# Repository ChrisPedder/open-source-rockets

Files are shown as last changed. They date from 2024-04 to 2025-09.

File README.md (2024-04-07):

# las_rocket_project
A repository for design files for the maker's workshop at LAS.

## Recommended software

To use the files in this repository, I recommend that you open the .ork file using [openrocket](https://openrocket.info/) which will allow you to view and modify the rocket design.

To create new nosecone designs, use the nosecone_factory.scad file, which can be opened with [openscad](https://openscad.org/). Scad format allows you to define .stl files in code, which makes it much easier to create parametrisable versions of things like nosecone designs.

Note that that nosecone is designed to be printed in PLA, with a wall thickness of 0.2mm, and with an infill density of 20%.

The nosecone_factory.scad is not my own work, but was created by Thingiverse user TZT, and is used here under Creative Commons - Attribution license.

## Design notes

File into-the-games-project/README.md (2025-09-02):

# Into the Games Rocket

An open source model rocket project designed for educational purposes and recreational flying. This rocket uses readily available components and 3D printed parts to create a stable, recoverable rocket suitable for D-class motors.

## Project Overview

This rocket is designed around a 50mm diameter mailing tube body with 3D printed motor mount, nose cone, and fin attachment system. The design prioritizes simplicity, safety, and repeatability while maintaining good aerodynamic performance.

**Key Specifications:**
- Body diameter: 50mm
- Motor: 18mm diameter (Klima D9-3 recommended)
- Recovery: 30cm parachute with kevlar shock cord
- Fin material: 4mm plywood
- Estimated flight altitude: ~150m (dependent on motor and conditions)

## Repository Contents

### Design Files

#### `into-the-games-rocket.ork`
OpenRocket simulation file containing the complete rocket design, stability analysis, and flight simulations.

**How to open:** Download and install [OpenRocket](http://openrocket.sourceforge.net/) (free, cross-platform), then open this .ork file to view simulations, modify the design, or analyze different motor configurations.

**What it contains:**
- Complete 3D model of the rocket
- Center of gravity and pressure calculations
- Stability margin analysis
- Flight simulation data for various motors
- Recovery system deployment timing

#### `fin-shape.svg`
Laser cutter template for the rocket fins.

**How to open:** Any vector graphics program (Inkscape, Adobe Illustrator, or even a web browser)

**Usage:** Send this file directly to a laser cutter set for 4mm plywood. The design includes 3 identical fins.

### 3D Printable Parts

All STL files are ready for 3D printing in PLA plastic with standard settings (0.2mm layer height, 20% infill).

#### `motor-mount.stl` / `motor-mount.scad`
**Purpose:** Houses the 18mm motor and provides attachment point for recovery system
**Features:**
- Precise 18mm motor tube fit
- Drill two 3mm holes in the top mounting ring shock cord attachment point
- Designed for friction fit into 50mm body tube, attachment with pva glue

#### `nose-cone.stl` / `nose-cone.scad`
**Purpose:** Aerodynamic nose cone with recovery system compartment
**Features:**
- Ogive shape for optimal aerodynamics
- Hollow interior, drill two 3mm holes for shock cord attachment
- Friction fit to body tube

#### `screw-cap.stl`
**Purpose:** Removable cap for motor mount access
**Features:** Threaded design for secure motor retention and easy motor changes

#### `fin-guide.stl`
**Purpose:** Alignment jig for precise fin attachment
**Features:** Ensures proper fin angle and spacing during assembly

### OpenSCAD Source Files

The `.scad` files are parametric source code for the 3D printed parts.

**How to open:** Download [OpenSCAD](https://openscad.org/) (free, open source)

**Benefits:**
- Modify dimensions for different body tubes or motors
- Adjust tolerances for your specific 3D printer
- Customize features like shock cord attachment points
- Generate parts for scaled versions

## Required Components

### Body Tube
**Part:** Mailing tube with plastic caps (50mm inner diameter × 310mm length)
**Source:** [Galaxus.ch](https://www.galaxus.ch/en/s12/product/kaiserkraft-mailing-tube-with-plastic-cap-and-base-lx-310-x-50-mm-brown-30-items-1-x-cardboard-boxes-43762165)
**Quantity:** 1 tube
**Notes:** Brown cardboard construction, includes plastic end caps

### Fins
**Material:** 4mm plywood
**Source:** Local laser cutting service or makerspace
**Quantity:** 3 fins (cut from `fin-shape.svg`)
**Dimensions:** Approximately 100mm × 80mm per fin

### 3D Printed Components
**Material:** PLA plastic
**Print Settings:**
- Layer height: 0.2mm
- Infill: 20%
- Supports: Only for nose cone if needed
**Parts:** Motor mount, nose cone, screw cap, fin guide

### Recovery System
**Parachute:** 30cm diameter
**Source:** [Amazon.de](https://www.amazon.de/TranRantic-Parachute-Children-Outdoor-Outdoors/dp/B0F7KQTMBR/)
**Shock Cord:** 1m of 2mm kevlar line
**Notes:** Kevlar is heat-resistant and won't burn from motor ejection charge

### Rail Guide
**Material:** 5mm paper drinking straw
**Length:** ~50mm
**Purpose:** Guides rocket on launch rod during initial acceleration, attached with pva glue

## Flight Components

### Motors
**Recommended:** Klima D9-3 (18mm diameter)
**Source:** [Hobbyshop.ch](https://www.hobbyshop.ch/modellraketen-treibsatz-d9-3-6-stueck-klima0493.html)
**Notes:**
- D9-3 provides good altitude (150m) with 3-second delay for recovery deployment
- Always verify motor fits properly before flight
- Store motors in cool, dry location

### Recovery Wadding
**Purpose:** Protects parachute from hot ejection gases
**Source:** [Hobbyshop.ch](https://www.hobbyshop.ch/schutzwatte-fuer-modellraketen-klima7020.html)
**Usage:** Pack wadding loosely into body tube below parachute before each flight

## Launch Equipment

### Launch Rod
**Specification:** 5mm diameter metal rod, minimum 1m length
**Purpose:** Guides rocket during initial acceleration until fins provide stability

### Safety Equipment
**Fire blanket:** Protects ground from motor flames
**Safety distance:** Minimum 30m from spectators
**Recovery area:** Large open field, minimum 200m radius

## Assembly Instructions
Full instructions and images can be found here (Making_a_rocket.pdf)

1. **Prepare body tube:** Remove plastic end caps, sand lightly if needed for 3D printed parts fit

2. **Attach shock cord to motor mount:** Tie a loop in the cord, one third along the length. Tie the long end of the cord to the two small holes in the motor mount using a figure of 8 knot.

3. **Install motor mount:** Press-fit motor mount into body tube, cord end first, threading the cord through the tube and out the other end. Ensure shock cord attachment is accessible.

4. **Attach shock cord to nose cone:** Tie the other end of the cord to the two small holes in the nose cone using a figure of 8 knot.

5. **Attach parachute:** Tie the end of the parachute lines to the loop already made in the shock cord. Attach with swivel if available.

6.  **Prepare recovery system:** Fold the parachute, wrap the cord around it and place it inside the rocket body tube. Fit the nose cone into the end of the body tube,  ensure smooth separation for recovery.

7. **Glue in motor mount:** Using Epoxy glue, glue the non-cord end of the motor mount into the end of the rocket body tube, so that the end of the motor tube is aligned with the end of the cardboard tube.

8. **Attach fins:** Use fin guide to mark positions, epoxy fins to body tube with 120° spacing. Ensure the end of the shallow sloping side of the fin is lined up with the end of the rocket body tube.

9. **Attach launch lug:** Take one launch lug (piece of drinking straw) and glue it between two fins, halfway along the rocket body tube.

## Pre-Flight Checklist

- [ ] Motor properly installed and retained
- [ ] Recovery wadding packed above parachute
- [ ] Parachute properly folded and not tangled
- [ ] Fin attachment secure
- [ ] Launch rod guide (straw) attached
- [ ] Weight and balance verified using OpenRocket file

## Safety Notes

⚠️ **Important Safety Information:**
- Always follow local regulations for model rockets
- Never attempt to make your own motors
- Inspect all components before each flight
- Maintain safe distances during launch
- Recovery area must be clear of dry vegetation
- Do not fly in high wind conditions (>20 km/h)

## Modifications and Customization

The OpenSCAD files allow easy customization:
- **Different body tubes:** Adjust outer diameter in motor-mount.scad
- **Alternative motors:** Modify motor mount inner diameter
- **Scaled versions:** Proportionally adjust all dimensions
- **Enhanced recovery:** Add dual-deploy or electronic altimeter bay

## Contributing

This is an open source project! Contributions welcome:
- Improved designs or alternative components
- Additional motor configurations
- Better assembly instructions
- Flight test data and photos

## License

This project is released under [Creative Commons Attribution-ShareAlike 4.0](https://creativecommons.org/licenses/by-sa/4.0/). You're free to use, modify, and share these designs as long as you provide attribution and share derivative works under the same license.

## Disclaimer

Model rocketry involves inherent risks. Users are responsible for following all local laws and safety guidelines. Always prioritize safety over performance. The authors are not responsible for damages or injuries resulting from the use of these designs.

---

**First time building rockets?** Consider joining [ARGOS](https://www.argoshpr.ch/j3/) a local rocketry club. The experience and mentorship are invaluable for safe, successful flights.

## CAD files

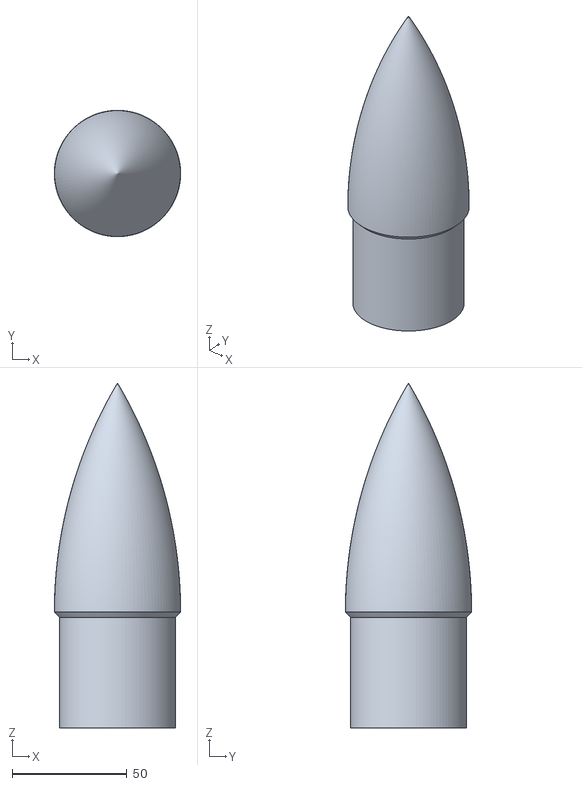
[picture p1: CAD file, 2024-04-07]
las-rocket-project/las_rocket_nosecone.stl
55.1 x 55.1 x 150.5

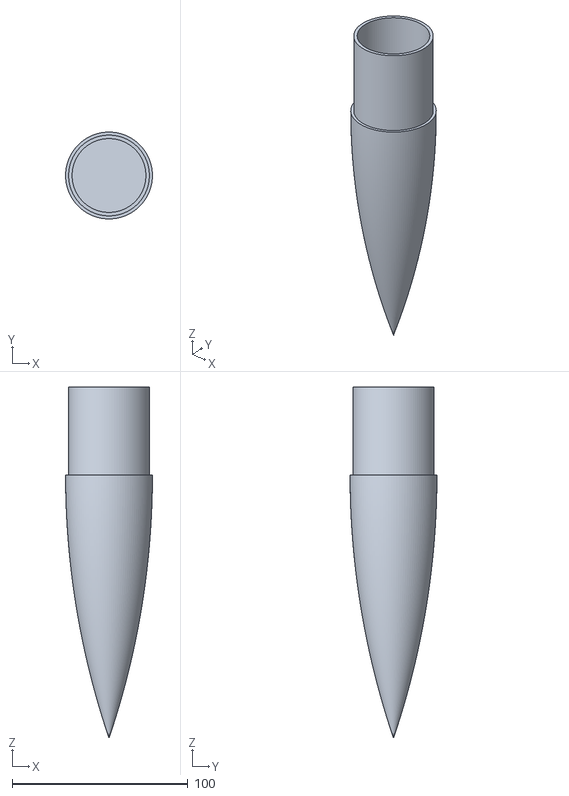
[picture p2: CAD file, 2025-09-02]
into-the-games-project/nose-cone.stl
49.5 x 49.5 x 199.9

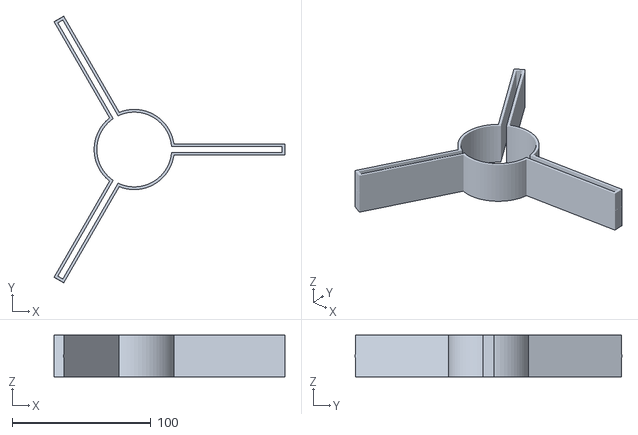
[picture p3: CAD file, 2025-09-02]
into-the-games-project/fin-guide.stl
166.6 x 192.4 x 30.0

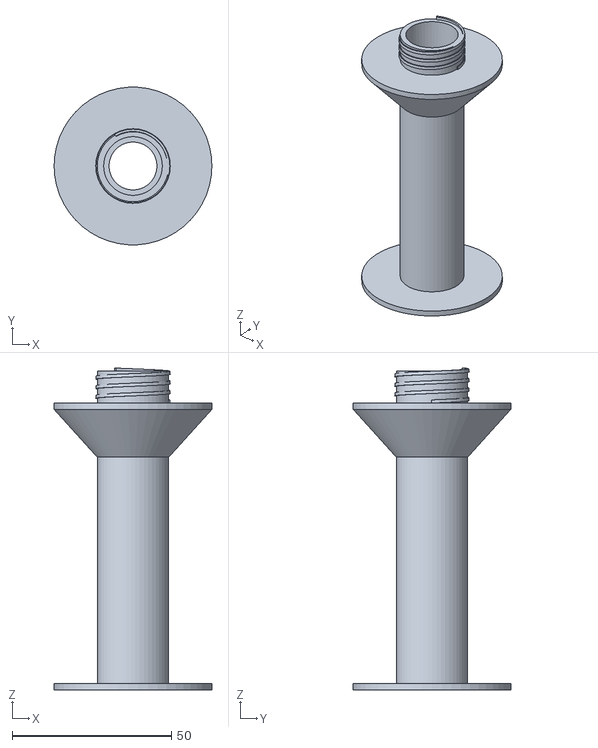
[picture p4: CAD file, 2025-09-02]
into-the-games-project/motor-mount.stl
49.5 x 49.4 x 101.0

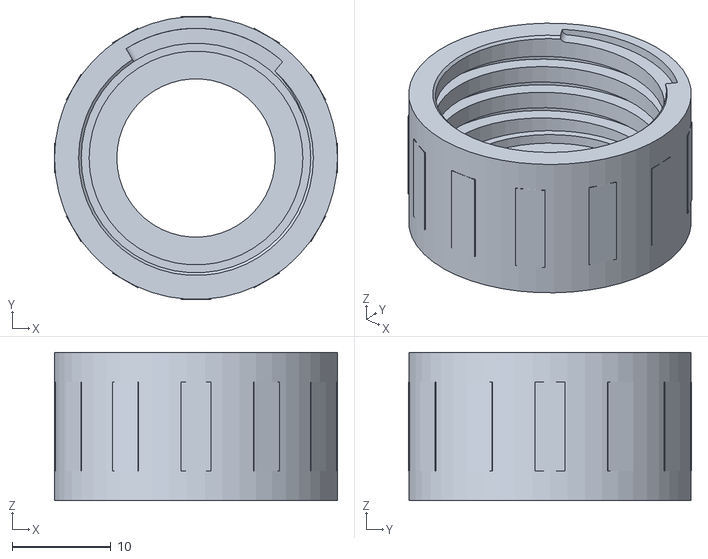
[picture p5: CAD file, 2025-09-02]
into-the-games-project/screw-cap.stl
28.6 x 28.6 x 15.0

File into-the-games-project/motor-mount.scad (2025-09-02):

// Rocket Motor Mount with Cap for 3D Printing - CONTINUOUS THREAD GROOVES
// All dimensions in millimeters

// Global Parameters
$fn = 50; // Reduced for faster rendering, increase to 100 for final print

// Main dimensions
inner_radius = 18.4 / 2;  // 9.2mm
wall_thickness = 2;
outer_radius = inner_radius + wall_thickness;  // 10.85mm
total_height = 100;

// Thread parameters
thread_length = 10;
thread_start = total_height - thread_length;  // 90mm from base
thread_pitch = 3;  // M22x1.5 metric thread
thread_depth = 1;  // Conservative depth to maintain wall strength
thread_thickness = 1;  // Controls thread thickness

// Internal retaining band parameters
band_distance_from_thread = 68.5;
band_position = total_height - band_distance_from_thread;  // 31.5mm from base
band_inner_radius = 15 / 2;  // 7.5mm
band_height = 3;

// External disc parameters
disc_outer_radius = 49.5 / 2;  // 24.75mm
disc_thickness = 2;
disc1_position = total_height - 12;  // 88mm from base
disc2_position = 0;  // At base

// Vent hole parameters for bottom disc
vent_hole_diameter = 3;
vent_hole_radius = vent_hole_diameter / 2;
vent_hole_separation = 10;  // Center to center

// Conical support parameters
cone_wall_thickness = 1.5;  // Wall thickness of the cone
cone_height = 15;  // Height of the conical support

// Cap parameters
cap_height = 15;  // Total height of cap
cap_wall_thickness = 2;
cap_top_thickness = 3;  // Thickness of top plate
cap_nozzle_radius = 16 / 2;  // 8mm radius for central hole
cap_clearance = 0.1;  // Clearance for thread fit (adjust based on printer)

// Module for creating external threads with finite thickness
module external_threads(height, radius, pitch, depth, thickness) {
    // Number of segments per turn for smoothness
    segments_per_turn = 36;
    total_angle = 360 * height / pitch;
    total_segments = segments_per_turn * height / pitch;
    
    // Generate thread as a series of small segments
    for(i = [0 : total_segments - 1]) {
        angle = i * total_angle / total_segments;
        z = i * height / total_segments;
        next_angle = (i + 1) * total_angle / total_segments;
        next_z = (i + 1) * height / total_segments;
        
        // Create each thread segment
        hull() {
            // Current position
            rotate([0, 0, angle])
            translate([radius, 0, z])
            rotate([90, 0, 0])
            linear_extrude(height = 0.1)
            polygon(points = [
                [-thickness/2, 0],
                [-thickness/2 * 0.7, depth],
                [thickness/2 * 0.7, depth],
                [thickness/2, 0]
            ]);
            
            // Next position
            rotate([0, 0, next_angle])
            translate([radius, 0, next_z])
            rotate([90, 0, 0])
            linear_extrude(height = 0.1)
            polygon(points = [
                [-thickness/2, 0],
                [-thickness/2 * 0.7, depth],
                [thickness/2 * 0.7, depth],
                [thickness/2, 0]
            ]);
        }
    }
}

// Module for main cylinder body
module main_cylinder() {
    difference() {
        // Outer cylinder
        cylinder(h = total_height, r = outer_radius);
        
        // Inner hollow
        cylinder(h = total_height, r = inner_radius);
    }
}

// Module for internal retaining band
module internal_band() {
    translate([0, 0, band_position]) {
        difference() {
            // Fill the internal space at this height
            cylinder(h = band_height, r = inner_radius);
            // Create the smaller opening
            cylinder(h = band_height, r = band_inner_radius);
        }
    }
}

// Module for conical support structure
module conical_support(disc_position) {
    translate([0, 0, disc_position - cone_height]) {
        difference() {
            // Outer cone (from disc radius at top to cylinder radius at bottom)
            cylinder(h = cone_height, 
                    r1 = outer_radius,  // Bottom radius (at cylinder)
                    r2 = disc_outer_radius);  // Top radius (at disc)
            
            // Inner cone (hollow it out to save material and reduce weight)
            translate([0, 0, -0.01])  // Slight offset to ensure clean difference
                cylinder(h = cone_height + 0.02, 
                        r1 = outer_radius - cone_wall_thickness,  // Bottom inner radius
                        r2 = disc_outer_radius - cone_wall_thickness);  // Top inner radius
            
            // Cut out the center to allow the main cylinder to pass through
            translate([0, 0, -0.01])
                cylinder(h = cone_height + 0.02, r = outer_radius + 0.01);
        }
    }
}

// Module for external mounting discs with vent holes
module mounting_disc(position, add_vent_holes = false) {
    translate([0, 0, position]) {
        difference() {
            cylinder(h = disc_thickness, r = disc_outer_radius);
            
            // Cut out center to fit around main cylinder
            cylinder(h = disc_thickness, r = outer_radius - 0.01);
            
            // Add vent holes if specified (for bottom disc)
            if (add_vent_holes) {
                // First vent hole
                translate([vent_hole_separation/2, 0, 0])
                    cylinder(h = disc_thickness + 1, r = vent_hole_radius);
                // Second vent hole
                translate([-vent_hole_separation/2, 0, 0])
                    cylinder(h = disc_thickness + 1, r = vent_hole_radius);
            }
        }
    }
}

// Complete motor mount assembly
module motor_mount() {
    union() {
        // Main cylinder body
        main_cylinder();
        
        // Add internal retaining band
        internal_band();
        
        // Add conical support for top disc
        conical_support(disc1_position);
        
        // Add external mounting disc (top, no vent holes)
        mounting_disc(disc1_position, false);
        
        // Add external mounting disc (bottom, with vent holes)
        mounting_disc(disc2_position, true);
        
        // Add threads to external surface
        translate([0, 0, thread_start])
            external_threads(thread_length, outer_radius, thread_pitch, thread_depth, thread_thickness);
    }
}

// NEW: Module for creating continuous internal thread grooves using hull operations
module continuous_internal_thread_groove(height, inner_radius, pitch, depth, groove_width) {
    // Number of segments per turn for smoothness
    segments_per_turn = 72;  // Increased for smoother groove
    total_segments = segments_per_turn * height / pitch;
    
    // Create continuous groove by hulling adjacent segments
    for(i = [0 : total_segments - 1]) {
        angle1 = i * 360 / segments_per_turn;
        z1 = i * height / total_segments;
        angle2 = (i + 1) * 360 / segments_per_turn;
        z2 = (i + 1) * height / total_segments;
        
        // Hull between consecutive positions to create continuous groove
        hull() {
            // First position
            rotate([0, 0, angle1])
            translate([inner_radius, 0, z1])
            rotate([0, 90, 0])
            cylinder(h = depth * 1.5, r = groove_width/2);
            
            // Second position
            rotate([0, 0, angle2])
            translate([inner_radius, 0, z2])
            rotate([0, 90, 0])
            cylinder(h = depth * 1.5, r = groove_width/2);
        }
    }
}

// Alternative method using polyhedron for truly continuous groove
module helical_thread_cutter(height, radius, pitch, depth, width) {
    // This creates a spiral cutting tool
    linear_extrude(height = height, twist = -360 * height / pitch, slices = height * 2)
    translate([radius, 0, 0])
    square([depth * 2, width], center = true);
}
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

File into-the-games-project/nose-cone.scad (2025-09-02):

// 3:1 Tangent Ogive Rocket Nose Cone with Shoulder
// All dimensions in millimeters

// Configurable Parameters
base_diameter = 53;        // Base diameter of nose cone (mm)
shoulder_diameter = 49.5;     // Shoulder diameter (mm)
shoulder_length = 50;       // Shoulder length (mm)
wall_thickness = 2;         // Wall thickness (mm)
cone_length = 150;          // Length of nose cone (mm)

// Resolution settings
$fn = 100;                  // Number of fragments for circles

// Calculate ogive parameters
radius = base_diameter / 2;
L = cone_length;
rho = (radius * radius + L * L) / (2 * radius);  // Radius of curvature

// Function to calculate ogive profile at height z
function ogive_radius(z, L, rho, radius) = 
    z >= 0 && z <= L ? 
    sqrt(rho * rho - (L - z) * (L - z)) + radius - rho : 
    0;

// Create the nose cone shape
module nose_cone_solid() {
    // Generate ogive profile points
    points = [
        for(i = [0:1:100]) 
            let(z = i * L / 100)
            [ogive_radius(z, L, rho, radius), z]
    ];
    
    // Add final point at base
    final_points = concat(points, [[0, L]]);
    
    // Rotate the profile to create 3D shape
    rotate_extrude(convexity = 10)
        polygon(final_points);
}

// Create the hollow nose cone with shoulder
module hollow_nose_cone() {
    difference() {
        union() {
            // Outer nose cone
            nose_cone_solid();
            
            // Outer shoulder
            translate([0, 0, L])
                cylinder(h = shoulder_length, 
                        r = shoulder_diameter / 2, 
                        center = false);
        }
        
        // Inner cavity for nose cone
        translate([0, 0, -0.01])  // Small offset to avoid z-fighting
        scale([(radius - wall_thickness) / radius, 
               (radius - wall_thickness) / radius, 
               (L - wall_thickness) / L])
            nose_cone_solid();
        
        // Inner cavity for shoulder (hollow tube)
        translate([0, 0, L - 0.01])
            cylinder(h = shoulder_length + 0.02, 
                    r = shoulder_diameter / 2 - wall_thickness, 
                    center = false);
    }
}

// Rotate for printing orientation (tip pointing up)
// Comment out the rotation if you want tip at origin pointing up
hollow_nose_cone();

// Display information
echo("=== Nose Cone Parameters ===");
echo(str("Base diameter: ", base_diameter, " mm"));
echo(str("Cone length: ", cone_length, " mm"));
echo(str("Shoulder diameter: ", shoulder_diameter, " mm"));
echo(str("Shoulder length: ", shoulder_length, " mm"));
echo(str("Wall thickness: ", wall_thickness, " mm"));
echo(str("Ogive radius of curvature: ", rho, " mm"));

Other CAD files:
las-rocket-project/nosecone_factory.scad

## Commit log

2024-04-07 adding first batch of files
    [las_rocket_nosecone.stl, nosecone_factory.scad]
2025-09-02 restructured files, added documentation for the into the games project
    [fin-guide.stl, las_rocket_nosecone.stl, motor-mount.scad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]
